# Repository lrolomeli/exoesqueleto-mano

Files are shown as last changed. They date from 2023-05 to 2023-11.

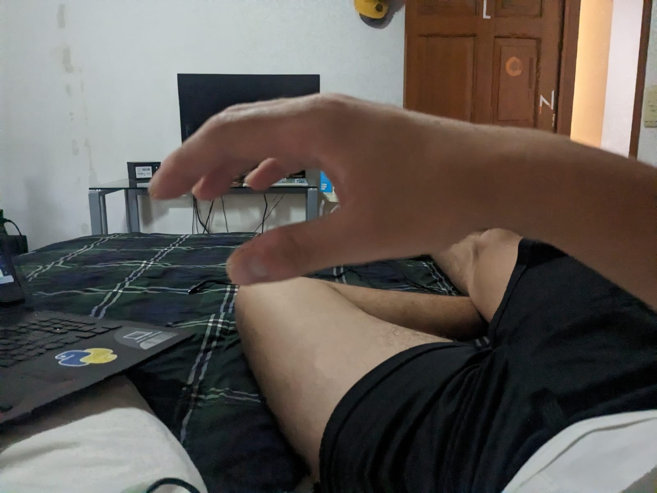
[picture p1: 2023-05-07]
imagenes/manoreal.jpeg

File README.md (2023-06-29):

# exoesqueleto-mano
Proyecto de biomédica, exoesqueleto motorizado para rehabilitación;
Interfaz Grafica Pyside Python,
Comunicacion Serial a través de módulo bluetooth serial HC-06,
Modelado en 3D en SolidWorks 2020, 
Impresion 3D Software Ultimaker Cura 4.13.1,
Software Embebido Diseñado en STM32 CubeIDE 1.12.1 HAL API BareMetal,
microcontrolador BluePill STM32F103C8T6,
controlador de motor a pasos A4988.
Bateria 12v motores de pasos de 12v y PCB diseñada en easyeda

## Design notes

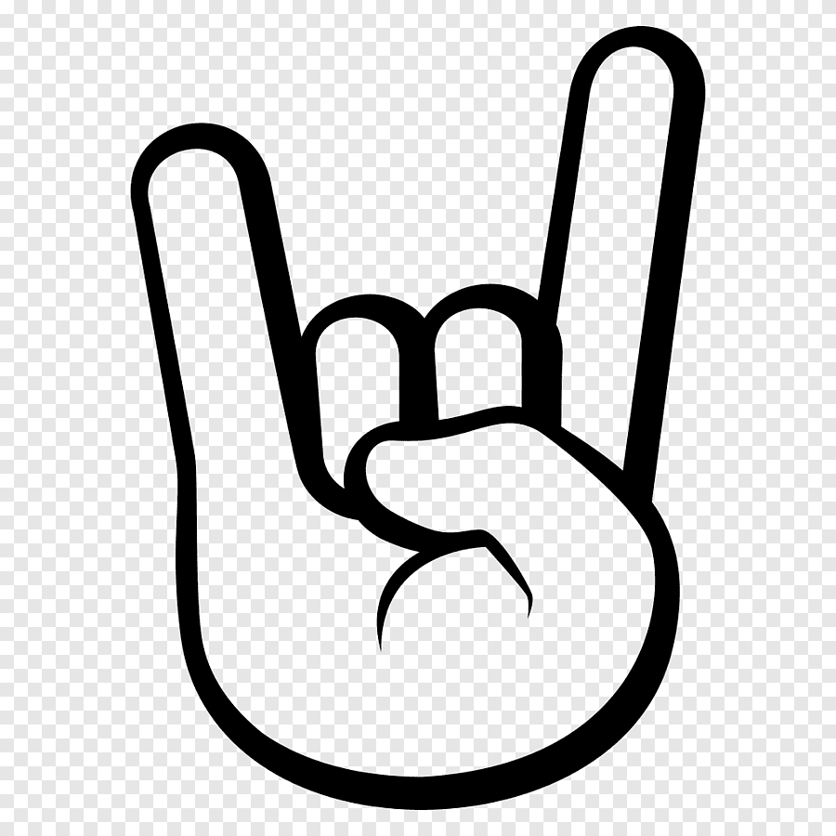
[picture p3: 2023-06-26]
programacion/pythongui/rockll.png

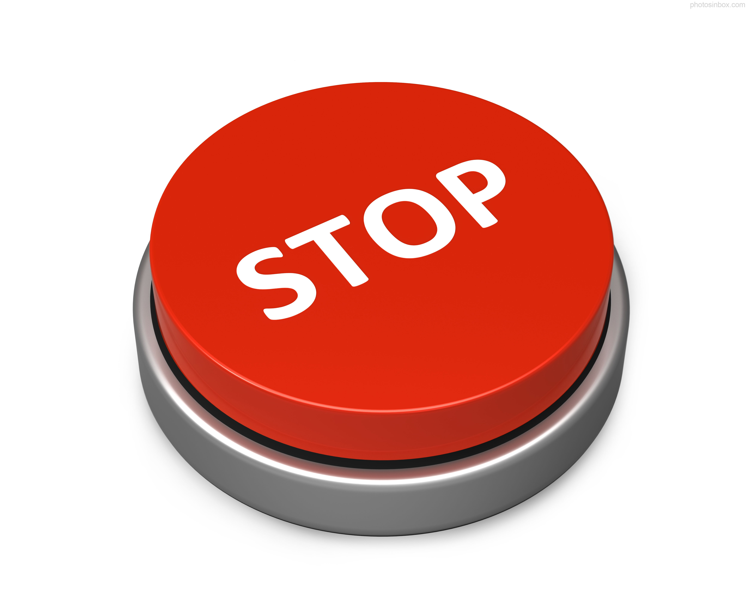
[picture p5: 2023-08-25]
programacion/pythongui/stop.png

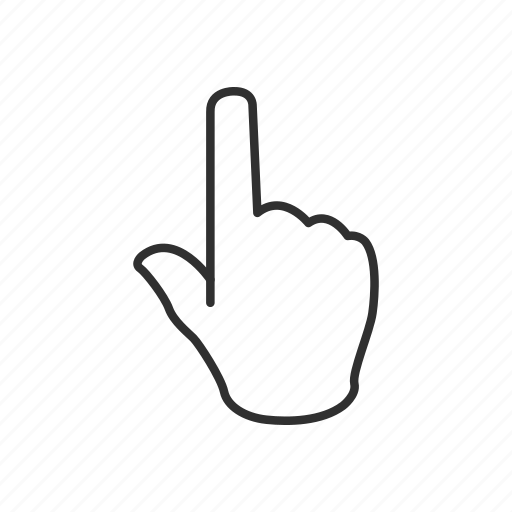
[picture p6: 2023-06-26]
programacion/pythongui/fup.png

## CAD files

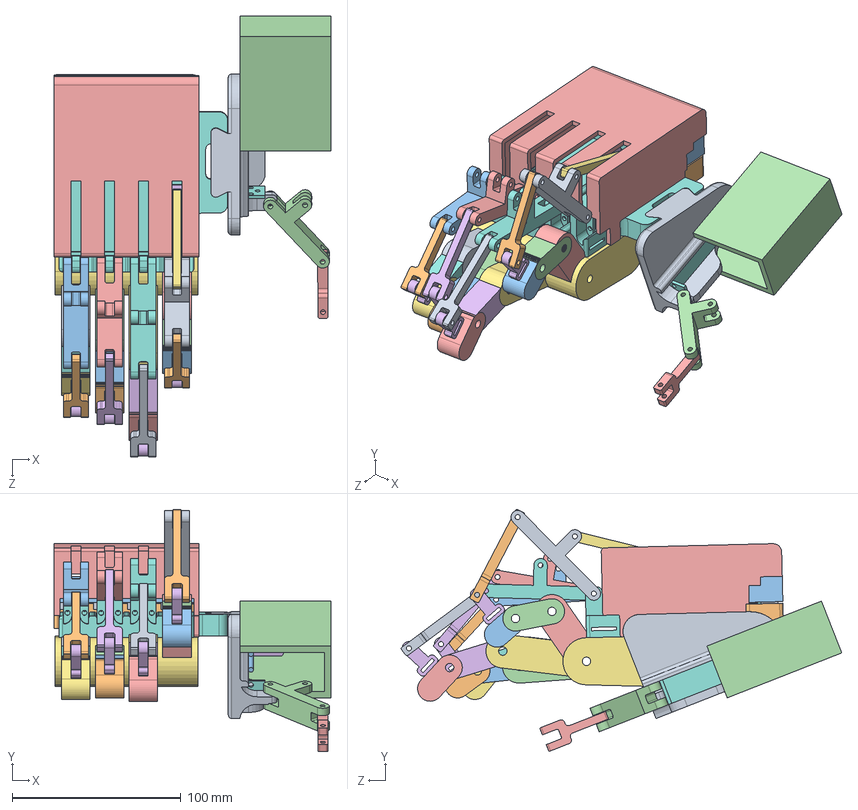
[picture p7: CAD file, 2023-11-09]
ensamble/ens_exo_unapieza.SLDASM
164.3 x 143.6 x 261.3 mm
palanca-indice
vastago-y-largo-indice
f1-indice
f2-indice
f3-indice
falangefinal x 4
vastago
guia-lineal x 5
motor15mm x 5
tornillo
perno-lineal x 4
union-motor_original
f1-medio
f2-medio
f3-medio
palanca-medio
vastago-y-largo-medio
f1-anular
f2-anular
f3-anular
palanca-anular
vastago-y-largo-anular
f1-menique
f2-menique
f3-menique
vastago-y-largo-menique
palanca-menique
_palanca-menique
vastago-y-largo-pulgar
abrazadera
torso-mano
base-principal-completa
base-principal-p2
abrazadera_completa_2pza
abrazadera_completa
cubierta_p
entronque

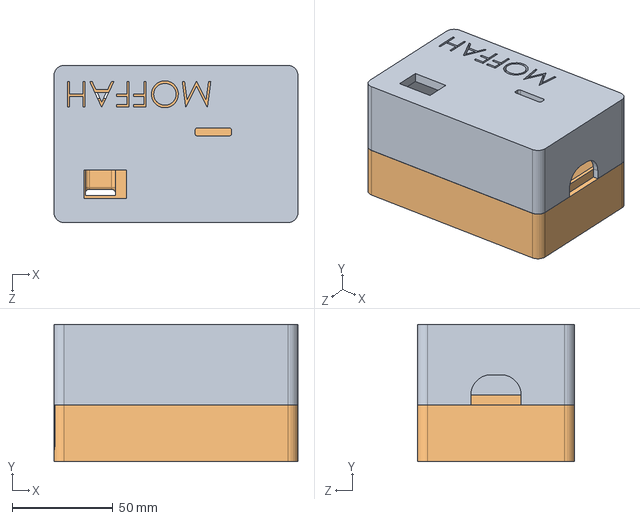
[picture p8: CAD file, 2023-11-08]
ensamble/ensamble base.SLDASM
121.0 x 68.1 x 78.0 mm
tapa_base
base_bateria_pcb_copia

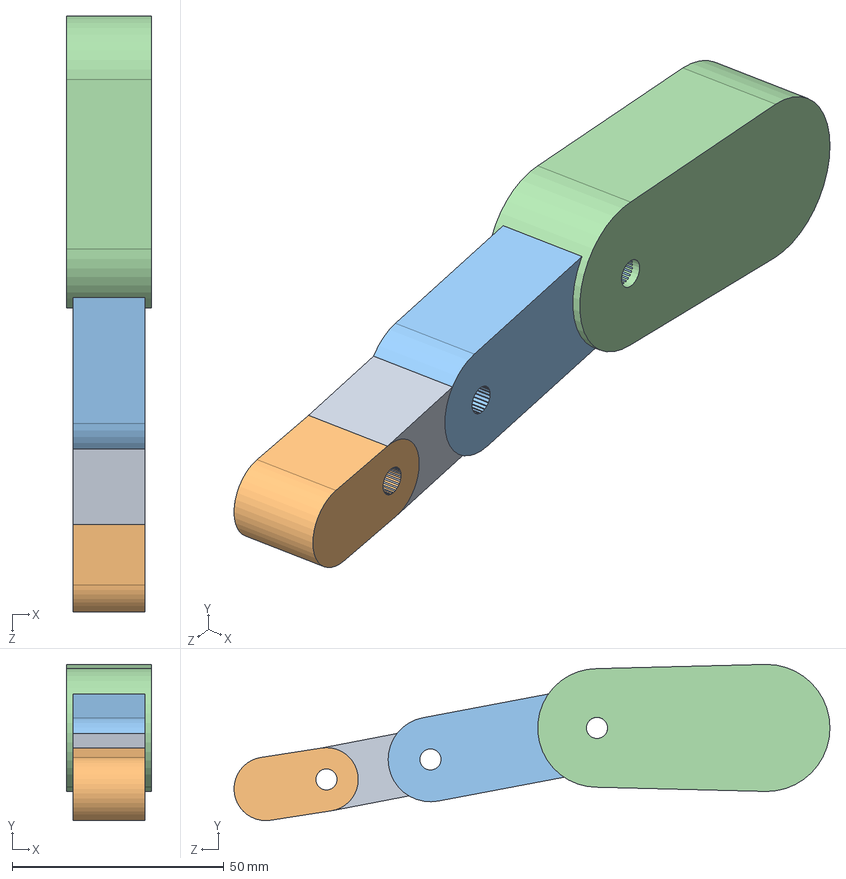
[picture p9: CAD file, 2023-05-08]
mano_p/Mano_p.SLDASM
20.0 x 36.9 x 140.7 mm
falange2_p
falange1_p
falange3_p
falange4_p

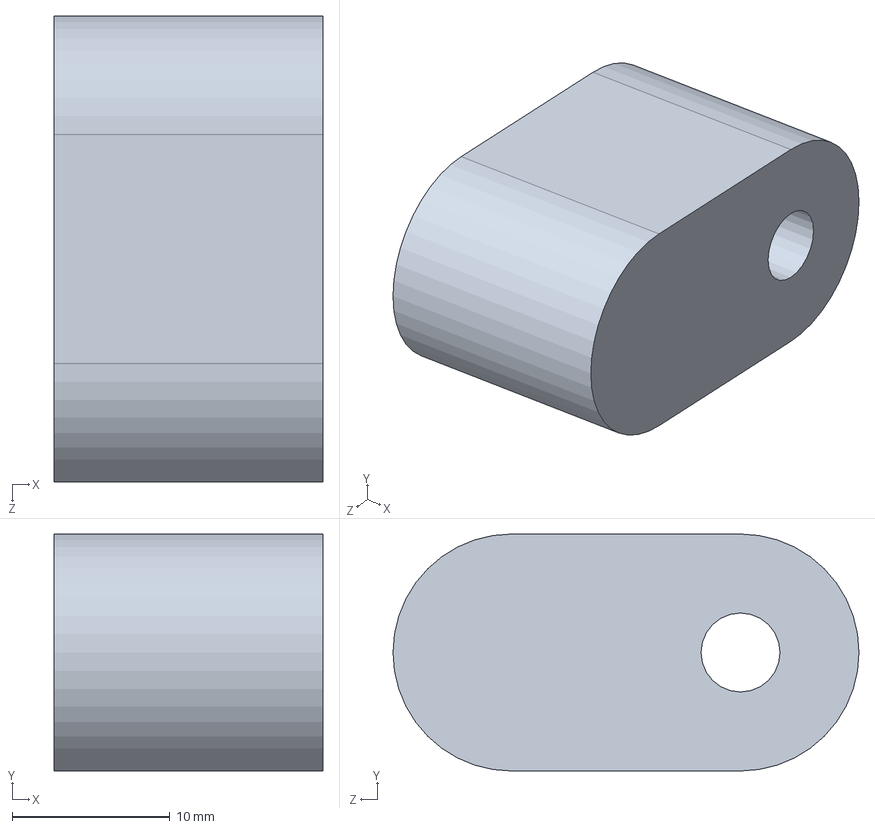
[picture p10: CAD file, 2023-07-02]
mano_p/f1-indice.SLDPRT
17.0 x 15.0 x 29.5 mm

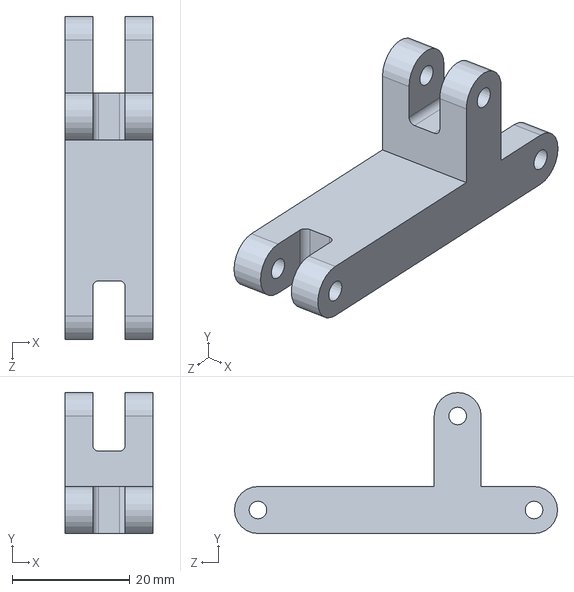
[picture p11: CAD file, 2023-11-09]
piezas/_palanca-menique.SLDPRT
15.0 x 24.0 x 55.0 mm

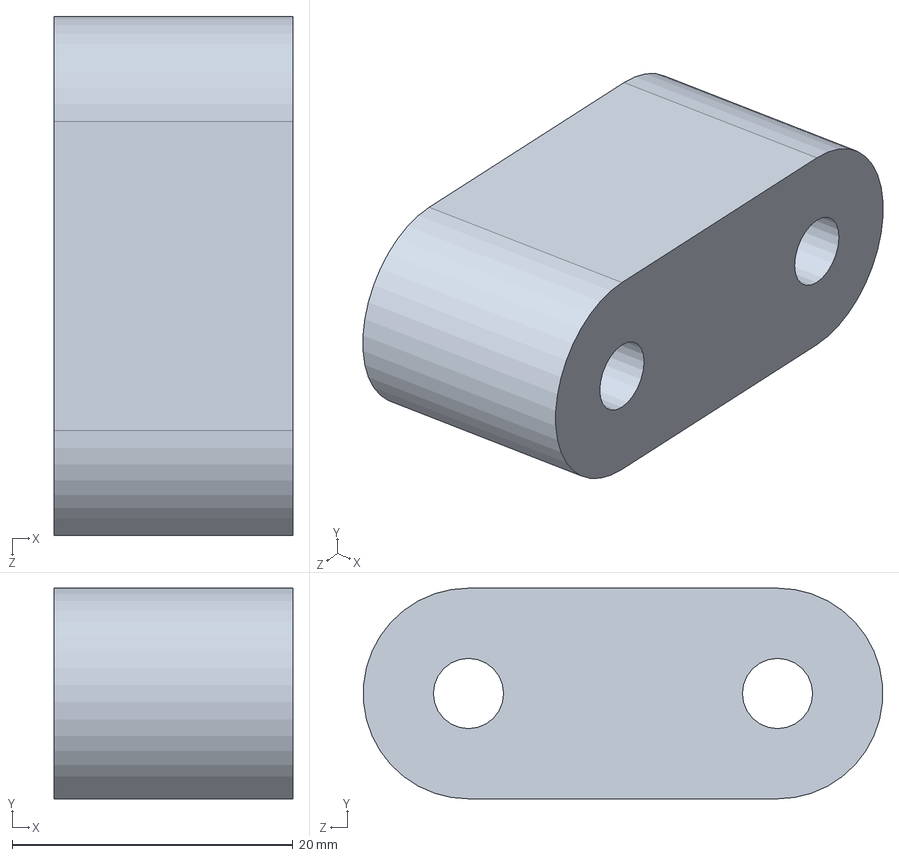
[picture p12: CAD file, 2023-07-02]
mano_p/f2-indice.SLDPRT
17.0 x 15.0 x 36.9 mm

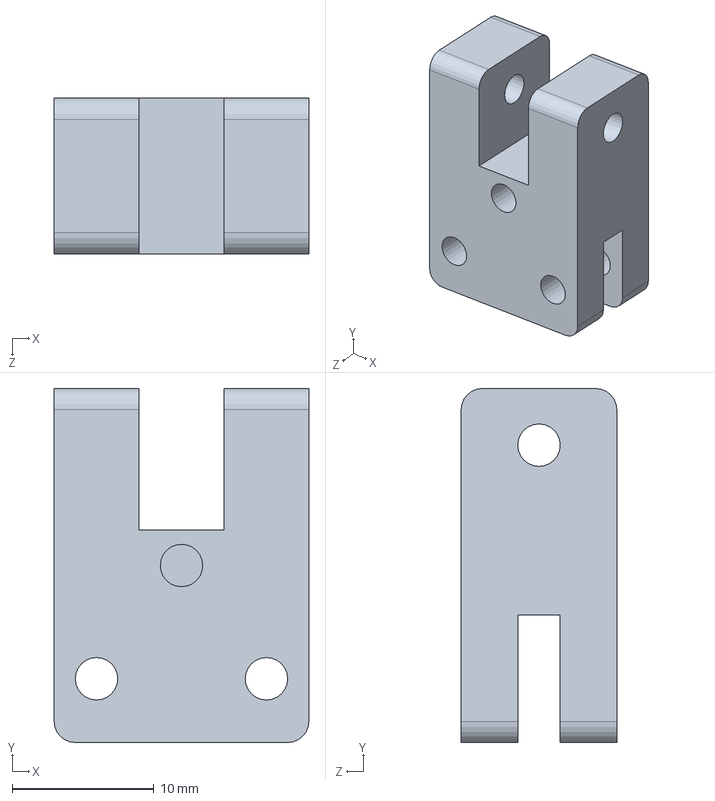
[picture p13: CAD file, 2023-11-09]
piezas/entronque.SLDPRT
18.0 x 25.0 x 11.0 mm

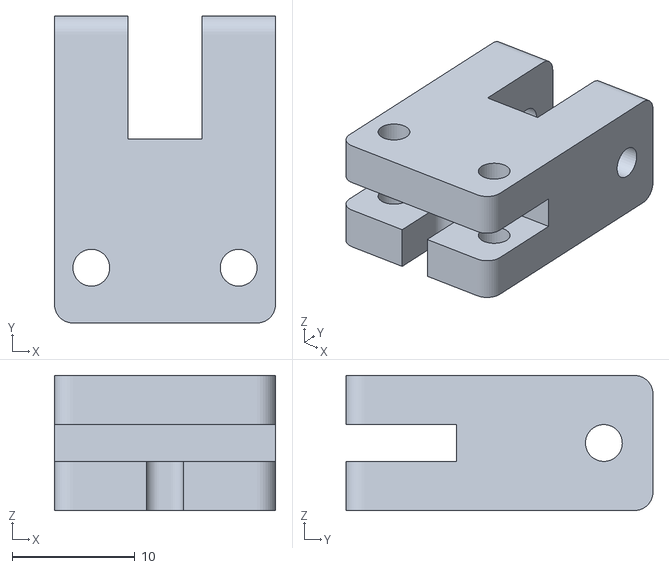
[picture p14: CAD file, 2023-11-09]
stl_impresion/entronque.STL
18.0 x 25.0 x 11.0

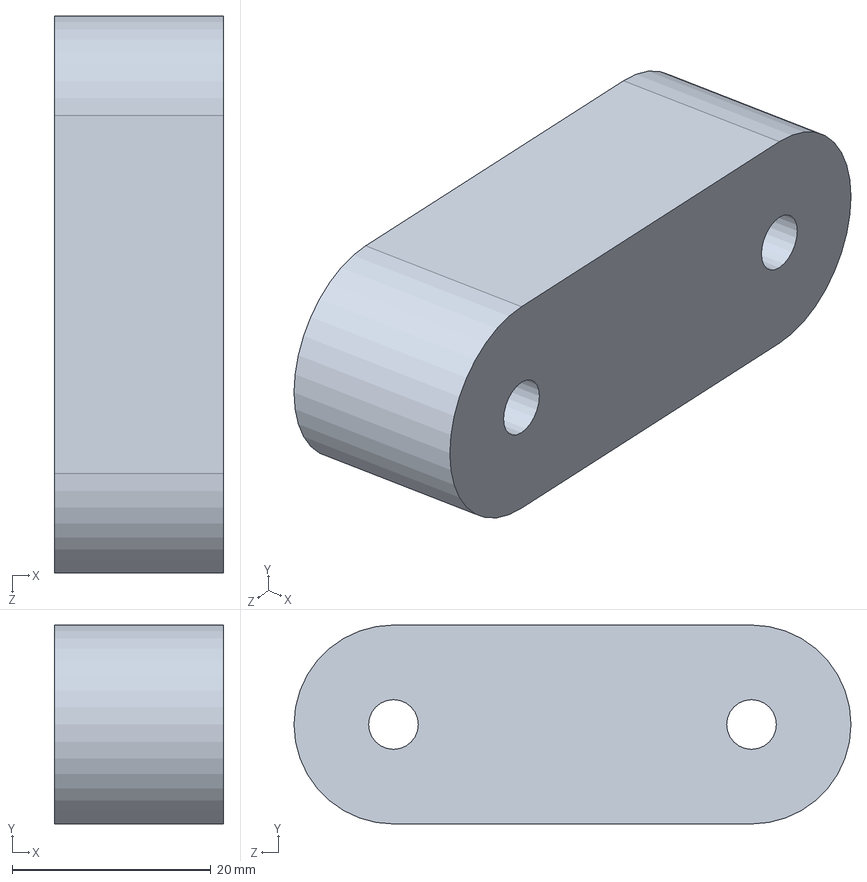
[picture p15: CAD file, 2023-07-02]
mano_p/f3-indice.SLDPRT
17.0 x 20.0 x 56.0 mm

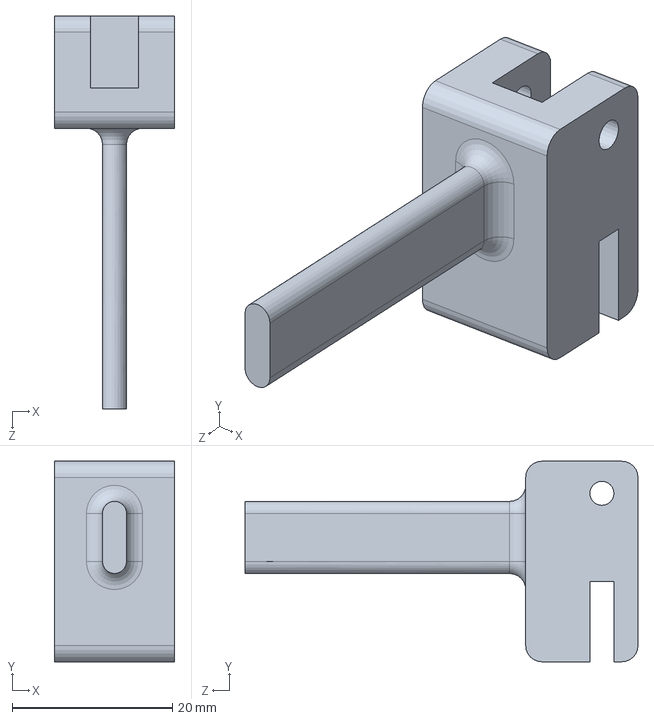
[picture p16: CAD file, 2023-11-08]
piezas/entronque_alto.SLDPRT
15.0 x 25.0 x 49.0 mm

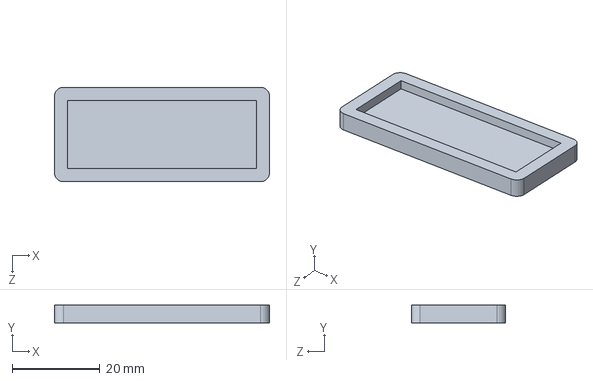
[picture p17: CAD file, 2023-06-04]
mano_p/reposamotor.SLDPRT
49.0 x 4.00 x 21.5 mm

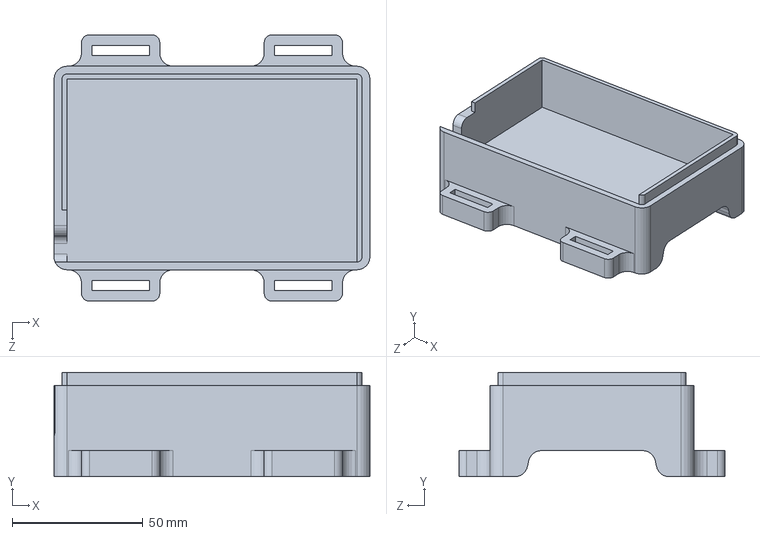
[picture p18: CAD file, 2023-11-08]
piezas/base_bateria_pcb.SLDPRT
121.0 x 40.0 x 102.0 mm

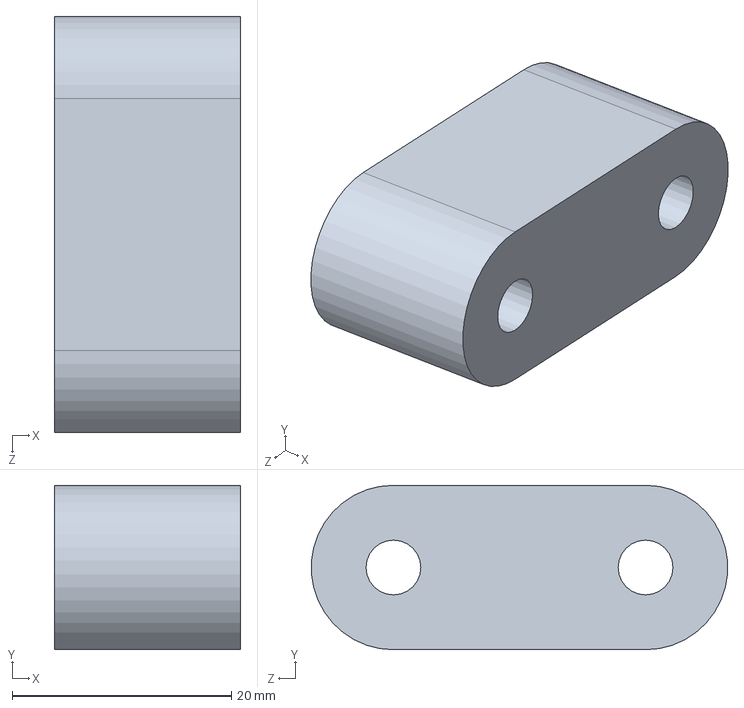
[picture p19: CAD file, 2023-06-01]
mano_p/f2-menique.SLDPRT
17.0 x 15.0 x 37.9 mm

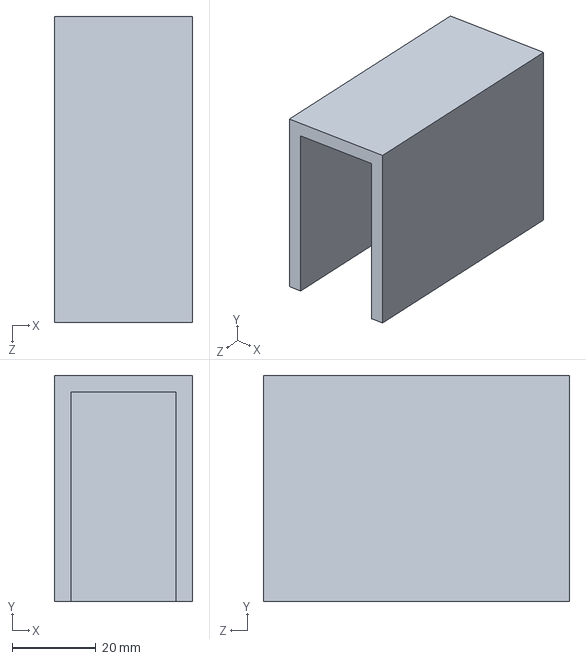
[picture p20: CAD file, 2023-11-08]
piezas/cubierta_p.SLDPRT
33.0 x 54.0 x 73.0 mm

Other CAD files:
stl_impresion/_palanca-menique.STL
stl_impresion/entronque_alto.STL
stl_impresion/cubierta1.STL
mano_p/f3-medio.SLDPRT
mano_p/f1-anular.SLDPRT
mano_p/f1-medio.SLDPRT
mano_p/f1-menique.SLDPRT
mano_p/f2-anular.SLDPRT
mano_p/f2-medio.SLDPRT
mano_p/f3-anular.SLDPRT
mano_p/f3-menique.SLDPRT
mano_p/falange4_p.SLDPRT
mano_p/torso-mano.SLDPRT
piezas/abrazadera.SLDPRT
piezas/abrazadera_completa.SLDPRT
piezas/abrazadera_completa_2pza.SLDPRT
piezas/base-principal-completa.SLDPRT
piezas/base-principal-p2.SLDPRT
piezas/base_bateria_pcb_copia.SLDPRT
piezas/cincho_belcro.SLDPRT
piezas/cubierta.SLDPRT
piezas/cubierta1.SLDPRT
piezas/entronque_barra_ref.SLDPRT
piezas/falangefinal.SLDPRT
piezas/guia-lineal.SLDPRT
piezas/motor15mm.SLDPRT
piezas/palanca-anular.SLDPRT
piezas/palanca-indice.SLDPRT
piezas/palanca-medio.SLDPRT
piezas/palanca-menique.SLDPRT
piezas/palanca-pulgar.SLDPRT
piezas/perno-lineal.SLDPRT
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

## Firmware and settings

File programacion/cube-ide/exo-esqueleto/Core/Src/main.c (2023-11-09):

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
/* Includes ------------------------------------------------------------------*/
#include "main.h"
#include "tim.h"
#include "usart.h"
#include "gpio.h"

/* USER CODE BEGIN PTD */
typedef enum{
	empty = 0,
	full
}enum_buffer_status;

typedef enum{
	Up = 0,
	Down,
	None
}enum_motion;

typedef enum{
	No = 0,
	Yes
}enum_bit_state;

typedef enum{
	Unreferenced = 0,
	Referenced
}enum_referenced;

typedef enum{
	GoHome = 0,
	WaitReleaseStage,
	GoInitialPosition,
	HomeRoutineComplete,
}enum_home_stages;


typedef enum{
	not_used = 0x00,
	reference_routine = 0x01,
	all_way_down  = 0x02,
	all_way_up  = 0x03,
	sinewave  = 0x04,
	gotoposition  = 0x05,
	reserved_plus=0x2B,
	reserved_minus=0x2D,
	reserved_major_C = 0x43,
	reserved_major_D = 0x44,
	nothing=0x74,
	deselect_thumb = 0x75,
	deselect_index = 0x76,
	deselect_middle = 0x77,
	deselect_ring = 0x78,
	deselect_little = 0x79,
	select_thumb = 0x7A,
	select_index = 0x7B,
	select_middle = 0x7C,
	select_ring = 0x7D,
	select_little = 0x7E,
	stop = 0x7F,
	speed_0 = 0xFA,
	speed_1 = 0xFB,
	speed_2 = 0xFC,
	speed_3 = 0xFD,
	speed_4 = 0xFE,
	speed_5 = 0xFF
}enum_action;

typedef enum{
	lost = 0,
	home,
	referenced
}enum_motor_status;

typedef enum{
	thumb = 0,
	index,
	middle,
	ring,
	little,
	flength
}enum_fingers;

typedef enum{
	portA = 0,
	portB,
}enum_ports;

typedef enum{
	normal = 0,
	fast = 1,
	as_hell

}enum_speed;

typedef enum{
	home_fs = 0,
	idle_fs,

}enum_fsm_state;

typedef struct{
	enum_bit_state in_operation;
	enum_fsm_state fsm_state;
	uint8_t bluetooth_command;
}st_exoesk;

typedef struct{
	uint16_t current_pos[flength];
	uint16_t go_to[flength];
	enum_bit_state fingers_in_op[flength];
	enum_bit_state fingers_in_pos[flength];
}st_gfinger_params;

typedef struct{
	const uint8_t port;
	const uint16_t pin;
}st_gpio_config_t;

typedef struct {
	const st_gpio_config_t step;
	const st_gpio_config_t direction;
	const st_gpio_config_t sleep;
}st_fconfig;

typedef void(*func_ptr_t)(st_exoesk * exoesk);

/* USER CODE END PTD */

/* USER CODE BEGIN PD */
//#define test

/* USER CODE END PD */


/* USER CODE BEGIN PV */

static const st_fconfig exoconfig[flength] = {
	/*       steps               direction                sleep                 home          */
	{ {portA, GPIO_PIN_1}, 	{portA, GPIO_PIN_0},   {portB, GPIO_PIN_4},	},//thumb
	{ {portB, GPIO_PIN_14},	{portB, GPIO_PIN_13},  {portB, GPIO_PIN_15}, },//index
	{ {portB, GPIO_PIN_1}, 	{portB, GPIO_PIN_0},   {portA, GPIO_PIN_8},	},//middle
	{ {portA, GPIO_PIN_6}, 	{portA, GPIO_PIN_5},   {portA, GPIO_PIN_7},	},//ring
	{ {portA, GPIO_PIN_3}, 	{portA, GPIO_PIN_2},   {portB, GPIO_PIN_3} }//little
};

static uint8_t times = 0;
static volatile uint8_t timeout_flg = 0;
static volatile enum_motor_status home_routine[flength] = {lost};
static volatile enum_buffer_status buffer_status = empty;
static volatile st_gfinger_params gfinger_params = { {0},{0},{0},{0} };

/* USER CODE END PV */

void SystemClock_Config(void);
/* USER CODE BEGIN PFP */

static void set_direction(uint8_t finger, GPIO_PinState dir);
static void sleep_motor(uint8_t finger);
static void motor_wakeup(uint8_t finger);
static void send_pulse(uint8_t finger);
static void clean_buffer(uint8_t * buf);
static void sinewave_fn(st_exoesk * exoesk);
static void preset_fingers_target(st_exoesk * exoesk, uint16_t position);
static void alive_fn(void);
static void send_step_pulses(st_exoesk * exoesk);
static void select_all_fingers(st_exoesk * exoesk);
static void deselect_all_fingers(st_exoesk * exoesk);
static void prepare_action(st_exoesk * exoesk);
static void dynamics(st_exoesk * exoesk);
static void home_f(st_exoesk * exoesk);
static void idle_f(st_exoesk * exoesk);
static void finger_default_conditions();
static uint8_t process_cmd(st_exoesk * exoesk);
static uint8_t fingers_in_position(void);
static void emergency_stop(void);
static void sleep_all_fingers(void);

/* USER CODE END PFP */

/* USER CODE BEGIN 0 */

static const func_ptr_t fsm_state[2] = {home_f, idle_f};

void HAL_UART_RxCpltCallback(UART_HandleTypeDef *huart){
	//waits until buffer is empty again
	if(empty == buffer_status)
	{
		buffer_status = full;
	}
}

void HAL_TIM_PeriodElapsedCallback(TIM_HandleTypeDef * htim)
{
	if(htim->Instance == TIM3)
	{
		if(timeout_flg==0)
		{
			timeout_flg = 1;
		}

	}

}

/* USER CODE END 0 */

/**
  * @brief  The application entry point.
  * @retval int
  */
int main(void)
{
  /* USER CODE BEGIN 1 */
	uint8_t halfms_cnt=0;
	st_exoesk exoesk = {No, home_fs, 0};
  /* USER CODE END 1 */

  /* MCU Configuration--------------------------------------------------------*/

  /* Reset of all peripherals, Initializes the Flash interface and the Systick. */
  HAL_Init();

  /* Configure the system clock */
  SystemClock_Config();

  /* Initialize all configured peripherals */
  MX_GPIO_Init();
  MX_USART3_UART_Init();
  MX_TIM3_Init();
  /* USER CODE BEGIN 2 */

	HAL_UART_Receive_IT(&huart3, &exoesk.bluetooth_command, sizeof(exoesk.bluetooth_command));
	htim3.Init.Period = htim3.Init.Period >> (normal);
	HAL_TIM_Base_Start_IT(&htim3);
	HAL_GPIO_WritePin(GPIOA, GPIO_PIN_4, GPIO_PIN_RESET);
	finger_default_conditions();
  /* USER CODE END 2 */

  /* Infinite loop */
  /* USER CODE BEGIN WHILE */
	while (1)
	{

		fsm_state[exoesk.fsm_state](&exoesk);

		if(timeout_flg)
		{

			if (halfms_cnt < times)
			{

				halfms_cnt++;
			}
			else
			{
				dynamics(&exoesk);
				halfms_cnt = 0;
			}
			alive_fn();
			timeout_flg = 0;

		}
    /* USER CODE END WHILE */

    /* USER CODE BEGIN 3 */
	}
  /* USER CODE END 3 */
}

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
/* USER CODE BEGIN 4 */

static void home_f(st_exoesk * exoesk)
{
	static enum_home_stages home_stage = GoHome;
	uint8_t finger = thumb;

	switch(home_stage)
	{
	case GoHome:
		// Seleccionamos los dedos que queremos mover en este caso todos.
		select_all_fingers(exoesk);
		// Situacion actual nos encontramos en la posicion 4095
		// Objetivo: movernos hacia la posicion CERO (0) (home)
		preset_fingers_target(exoesk, ZERO_POSITION);
		// Esperar a que se despejen los motores
		home_stage = WaitReleaseStage;
		break;
	case WaitReleaseStage:
		if(No == exoesk->in_operation)
		{
			// Definimos el objetivo al que hay que movernos. Los pasos necesarios para volver al boton
			preset_fingers_target(exoesk, HOME_POSITION);
			home_stage = GoInitialPosition;
		}
		break;

	case GoInitialPosition:
		if(No == exoesk->in_operation)
		{
			for(finger=thumb; finger<flength; finger++)
			{
				home_routine[finger] = referenced;
			}
			deselect_all_fingers(exoesk);
			home_stage = HomeRoutineComplete;
			exoesk->fsm_state = idle_fs;
		}
		break;
	case HomeRoutineComplete:
		// Comenzamos con condiciones iniciales
		finger_default_conditions();
		home_stage = GoHome;
		break;
	default:
		break;
	}

}

static void idle_f(st_exoesk * exoesk)
{

	if(full == buffer_status)
	{
		prepare_action(exoesk);
		clean_buffer(&exoesk->bluetooth_command);
		HAL_UART_Receive_IT(&huart3, &exoesk->bluetooth_command, sizeof(exoesk->bluetooth_command));
	}

}

static void dynamics(st_exoesk * exoesk)
{
	if(exoesk->in_operation)
	{
		/* Move fingers */
		send_step_pulses(exoesk);
	}

}

static void prepare_action(st_exoesk * exoesk)
{
	static uint8_t cmd_complete = 1;
	uint16_t steps = 0;

	if(cmd_complete == 0)
	{
		steps = exoesk->bluetooth_command * 25;
		preset_fingers_target(exoesk, (steps<<SYS_USED_STEP));
		cmd_complete = 1;
	}
	else
	{
		cmd_complete = process_cmd(exoesk);
	}
}

static uint8_t process_cmd(st_exoesk * exoesk)
{
	switch(exoesk->bluetooth_command)
	{
	case not_used:
		break;
	case reference_routine:
		exoesk->fsm_state = home_fs;
		break;
	case all_way_down:
		preset_fingers_target(exoesk, ZERO_POSITION);
		break;
	case all_way_up:
		preset_fingers_target(exoesk, MAX_POSITION);
		break;
	case sinewave:
		sinewave_fn(exoesk);
		break;
	case gotoposition:
		return 0;
		break;
	case reserved_major_C:
		break;
	case deselect_thumb:
		gfinger_params.fingers_in_op[thumb] = No;
		break;
	case deselect_index:
		gfinger_params.fingers_in_op[index] = No;
		break;
	case deselect_middle:
		gfinger_params.fingers_in_op[middle] = No;
		break;
	case deselect_ring:
		gfinger_params.fingers_in_op[ring] = No;
		break;
	case deselect_little:
		gfinger_params.fingers_in_op[little] = No;
		break;
	case select_thumb:
		gfinger_params.fingers_in_op[thumb] = Yes;
		break;
	case select_index:
		gfinger_params.fingers_in_op[index] = Yes;
		break;
	case select_middle:
		gfinger_params.fingers_in_op[middle] = Yes;
		break;
	case select_ring:
		gfinger_params.fingers_in_op[ring] = Yes;
		break;
	case select_little:
		gfinger_params.fingers_in_op[little] = Yes;
		break;
	case stop:
		sleep_all_fingers();
		exoesk->in_operation = No;

		break;
	case speed_1:
	case speed_2:
	case speed_3:
	case speed_4:
	case speed_5:
		times = exoesk->bluetooth_command - speed_0;
		break;
	default:
		break;
	}
	return 1;

}

static void select_all_fingers(st_exoesk * exoesk)
{
	for(uint8_t finger=thumb; finger<flength; finger++)
	{
		gfinger_params.fingers_in_op[finger] = Yes;
	}
}

static void deselect_all_fingers(st_exoesk * exoesk)
{
	for(uint8_t finger=thumb; finger<flength; finger++)
	{
		gfinger_params.fingers_in_op[finger] = No;
	}
}

static void sleep_all_fingers(void)
{
	for(uint8_t finger=thumb; finger<flength; finger++)
	{
		sleep_motor(finger);
	}
}

static void send_step_pulses(st_exoesk * exoesk)
{
	uint8_t finger = thumb;
	for(finger = thumb; finger < flength; finger++)
	{
		if(gfinger_params.fingers_in_op[finger])
		{
			/* when finger is selected to be moved */
			if(gfinger_params.go_to[finger] == gfinger_params.current_pos[finger])
			{
				/* when finger has reached expected position */
				sleep_motor(finger);
				gfinger_params.fingers_in_pos[finger] = Yes;
			}
			else
			{
				/* finger has not reached expected position */
				send_pulse(finger);
				if(gfinger_params.go_to[finger] > gfinger_params.current_pos[finger])
				{
					gfinger_params.current_pos[finger]++;
				}
				else
				{
					gfinger_params.current_pos[finger]--;
				}
			}
		}
	}

	/* if all fingers are in position we should sleep the system */
	if(fingers_in_position())
	{
		exoesk->in_operation = No;
	}
	else
	{
		exoesk->in_operation = Yes;
	}

}

static void alive_fn(void)
{
	static uint16_t var = 2000;

	if(var > 0)
	{
		var--;
	}
	else
	{
		var = 2000;
		HAL_GPIO_TogglePin(GPIOC, GPIO_PIN_13);
	}
}

static void finger_default_conditions()
{
	for(uint8_t finger=thumb; finger<flength; finger++)
	{
		/* el dedo no esta en operacion */
		gfinger_params.fingers_in_op[finger] = No;
		/* la rutina de home no se ha completado */
		home_routine[finger] = lost;
		/* no se conoce la posicion del motor */
		gfinger_params.current_pos[finger] = SCREW_LEN_IN_STEP;
		/* no se ha determinado la posicion a la que vamos a movernos */
		gfinger_params.go_to[finger] = ZERO_POSITION;
		/* el dedo esta en cierta posicion y por lo tanto no se esta moviendo */
		gfinger_params.fingers_in_pos[finger] = Yes;
	}
}

static void sinewave_fn(st_exoesk * exoesk)
{

}

/**
 * preset_fingers_target function
 *
 * 1) Revisa cual dedo se encuentra habilitado para moverse.
 * 2) Establece el objetivo al que hay que mover cada dedo
 * 3)
 *
 */
static void preset_fingers_target(st_exoesk * exoesk, uint16_t position)
{
	uint8_t finger = thumb;
	for(finger=thumb; finger<flength; finger++)
	{
		if(gfinger_params.fingers_in_op[finger])
		{
			gfinger_params.fingers_in_pos[finger] = No;
			gfinger_params.go_to[finger] = position;
			// opc1 -> si la posicion actual es mayor a la posicion final
			if (gfinger_params.current_pos[finger] > position)
			{
				set_direction(finger, Down);
				motor_wakeup(finger);
			}
			else if(gfinger_params.current_pos[finger] < position)
			{
				// si la posicion final es mayor al maximo
				if(MAX_POSITION < position)
				{
					gfinger_params.go_to[finger] = MAX_POSITION;
				}
				set_direction(finger, Up);
				motor_wakeup(finger);
			}
			else
			{
				// current position is not the same as goto position
				gfinger_params.go_to[finger] = gfinger_params.current_pos[finger];
				gfinger_params.fingers_in_pos[finger] = Yes;
			}
		}
	}

	/* if all fingers are in position we should do nothing */
	if(fingers_in_position())
	{
		exoesk->in_operation = No;
	}
	else
	{
		exoesk->in_operation = Yes;
	}

}

static uint8_t fingers_in_position()
{
	return (gfinger_params.fingers_in_pos[thumb] &&
			gfinger_params.fingers_in_pos[index] &&
			gfinger_params.fingers_in_pos[middle] &&
			gfinger_params.fingers_in_pos[ring] &&
			gfinger_params.fingers_in_pos[little]);
}

static void clean_buffer(uint8_t * buf)
{
	*buf = 0;
	buffer_status = empty;
}

static void emergency_stop(void)
{
	HAL_GPIO_WritePin(GPIOA, GPIO_PIN_4, GPIO_PIN_SET);
}

static void sleep_motor(uint8_t finger)
{
	if(exoconfig[finger].sleep.port == portA)
		HAL_GPIO_WritePin(GPIOA, exoconfig[finger].sleep.pin, GPIO_PIN_RESET);
	else
		HAL_GPIO_WritePin(GPIOB, exoconfig[finger].sleep.pin, GPIO_PIN_RESET);
}

static void motor_wakeup(uint8_t finger)
{
	if(exoconfig[finger].sleep.port == portA)
		HAL_GPIO_WritePin(GPIOA, exoconfig[finger].sleep.pin, GPIO_PIN_SET);
	else
		HAL_GPIO_WritePin(GPIOB, exoconfig[finger].sleep.pin, GPIO_PIN_SET);
}

static void send_pulse(uint8_t finger)
{
	if(exoconfig[finger].step.port == portA)
		HAL_GPIO_TogglePin(GPIOA, exoconfig[finger].step.pin);
	else
		HAL_GPIO_TogglePin(GPIOB, exoconfig[finger].step.pin);
}

static void set_direction(uint8_t finger, GPIO_PinState dir)
{

	if(exoconfig[finger].direction.port == portA)
		HAL_GPIO_WritePin(GPIOA, exoconfig[finger].direction.pin, dir);
	else
		HAL_GPIO_WritePin(GPIOB, exoconfig[finger].direction.pin, dir);
}

/* USER CODE END 4 */
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


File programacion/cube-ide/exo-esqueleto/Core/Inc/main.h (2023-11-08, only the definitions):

#define Full_Step 		(0U)
#define Half_Step 		(1U)
#define Quarter_Step 	(2U)
#define Eigth_Step 		(3U)
#define Sixteen_Step 	(4U)
#define SYS_USED_STEP (Half_Step)
#define SCREW_LEN_IN_STEP ((4095)<<(SYS_USED_STEP))
#define Initial_Position 	((3000U)<<(SYS_USED_STEP))
#define HOME_POSITION 		((300U)<<(SYS_USED_STEP))
#define UNDEFINED 		((4095U)<<(SYS_USED_STEP))
#define NOT_KNOWN_POSITION (0U)
#define MAX_POSITION 	((3200U)<<(SYS_USED_STEP))
#define ZERO_POSITION 	(0U)

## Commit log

2023-04-27 primer registro de las piezas del exoesqueleto, ensamble y archivos de impresion
    [coplemotor_tornillo.SLDPRT, coplemotor_tornillo.STL, ensamble-exoesqueleto.SLDASM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]
2023-04-27 ruta relativa de archivos de piezas del ensamble agregada
    [ensamble-exoesqueleto.SLDASM]
2023-05-07 new branch to make my design ideas
    [ensamble-exoesqueleto.SLDASM, falange.SLDPRT, falange_s.SLDPRT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]
2023-05-07 nuevos cambios
    [ensamble-exoesqueleto.SLDASM, falange.SLDPRT, soporte de union.SLDPRT]
2023-05-07 rediseño de exoesqueleto
    [ensamble-exoesqueleto.SLDASM, soporte de falange.SLDPRT, soporte de union.SLDPRT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]
2023-05-08 falange dinamica
    [ensamble-exoesqueleto.SLDASM, falange.SLDPRT, falange.STL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]
2023-05-08 palanca funcionando
    [Mano_p.SLDASM, conector.SLDPRT, ensamble-exoesqueleto.SLDASM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]
2023-05-08 cambio de nombre a base principal
    [base-principal.SLDPRT, base-principal.STL, ensamble-exoesqueleto.SLDASM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]
2023-05-20 ensamble mano completa
    [ensamble-exocompleto.SLDASM, ensamble-exoesqueleto.SLDASM, falange.SLDPRT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]
2023-05-20 modificaciones al diseño ampliar medidas en puntos criticos de impresion como los cortes circulares ampliar ajustes de piezas ensambladas corregir la pieza vastago en y alargar el palo centrar mas el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
    [ensamble-exocompleto.SLDASM, falange.SLDPRT, palanca-falange.SLDPRT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]
2023-05-29 ensamble modificado, programa v0.0 comenzado
    [base-principal-completa.SLDPRT, base-principal.STL, coplemotor_tornillo.STL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]
2023-05-29 programa 1 mover motor casi listo
2023-06-01 prototipo final dedos listos falta pulgar
    [base-principal-completa.SLDPRT, base-principal.SLDPRT, conector.SLDPRT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]
2023-06-01 pulgar agregado al ensamble
    [base-principal-completa.SLDPRT, ens_exo_unapieza.SLDASM, guia-lineal.SLDPRT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]
2023-06-04 cambios en el codigo
    [base-principal-completa.SLDPRT, ens_exo_unapieza.SLDASM, reposamotor.SLDPRT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]
2023-06-04 codigo under test uart enable off
2023-06-05 interrupciones externas para botones de home listas, motor en prueba movimiento continuo, comunicacion bluetooth lista, pwm listo por si se necesita, timer para frecuencia del motor 1ms
2023-06-09 programa listo para mover un dedo con comandos bluetooth
2023-06-12 fixes en la rutina de referencia en codigo, piezas nuevas para fijar push buttons fisicos y de referencia a posicion cero
2023-06-12 modificaciones al ensamble y piezas nuevas
    [abrazadera.SLDPRT, abrazadera.STL, ens_exo_unapieza.SLDASM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]
2023-06-12 division en piezas de base principal
    [base-principal-completa.SLDPRT, base-principal-p1.SLDPRT, base-principal-p1.STL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]
2023-06-12 nuevo diseño pieza base principal
    [base-principal-p1.SLDPRT]
2023-06-12 ensamble sin errores nueva base pieza principal
    [_base-principal-completa.SLDPRT, base-principal-completa.SLDPRT, base-principal-p1.SLDPRT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]
2023-06-16 base principal 2da pieza lista
    [_base-principal-completa.SLDPRT, base-principal-completa.SLDPRT, base-principal-p2.SLDPRT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]
2023-06-24 quitando senales pwm que no se necesitan
2023-06-24 desconfiguracion pwm de los pines
2023-06-25 modificaciones en el codigo para agregar mas motores y entradas
2023-06-26 interfaz de usuario lista
2023-06-28 campos de bits reemplazados por arreglo de enteros, mas faciles de utilizar y dar mantenimiento
2023-06-29 there are still bugs when referencing or going back and forth
    [exoesqueleto.py, gui.py, main.c]
2023-06-29 fixed logic to home reference
    [main.c]
2023-06-29 limpiando piezas desactualizadas del ensamble
    [ens_exo_unapieza.SLDASM, palanca-anular.SLDPRT, palanca-medio.SLDPRT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]
2023-06-30 entronque modificado
    [ens_exo_unapieza.SLDASM, entronque_alto.SLDPRT, entronque_barra_ref.SLDPRT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]
2023-06-30 eliminando archivos no utilizados en el ensamble
    [_base-principal-completa.SLDPRT, coplemotor_tornillo.SLDPRT, ens_exo_unapieza.SLDASM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]
2023-06-30 eliminando archivos temporales de impresion y 2d
    [abrazadera.STL, base-principal-p1.STL, base-principal-p2.STL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]
2023-06-30 pines de todo el sistema configurado
2023-07-01 probando con distintas velocidades
2023-07-02 nuevas piezas y modificaciones al ensamble
    [abrazadera.STL, base-principal-p2.SLDPRT, ens_exo_unapieza.SLDASM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]
2023-07-02 medidas de piezas modificadas para mano de rubi
    [base-principal-completa.SLDPRT, base-principal-p2.SLDPRT, ens_exo_unapieza.SLDASM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]
2023-07-03 thumb finger working bug fixed
    [abrazadera.SLDPRT, abrazadera_completa.SLDPRT, abrazadera_completa.STL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]
2023-07-03 funcionan todos los dedos aun hay que resolver muchos bugs
    [main.c, main.h]
2023-07-04 bugs en rutina de home arreglados distancia maxima corregida
    [gui.py, main.c, main.h]
2023-07-09 nuevas piezas para el sobrecalentamiento de los motores
    [abrazadera_completa.SLDPRT, abrazadera_completa.STL, abrazadera_completa_2pza.SLDPRT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]
2023-07-16 ultimos cambios
    [base_bateria_pcb.SLDPRT]
2023-07-24 funcionalidad de angulo y velocidad implementada
2023-07-24 variable timer to pulses for motor speed
2023-07-28 mis cambios en la gui
2023-08-06 variables de velocidad y pasos en seccion de recepcion de comandos
2023-08-19 rutina de home arreglada ahora los botones van primero hacia abajo (adelante) y despues regresan a tocar el boton home
    [main.c]
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2023-08-20 nueva version compilable de codigo, rutina de home mas robusta falta hacer pruebas
2023-08-20 seleccion de dedos correcta
    [gui.py, main.c, main.h]
2023-08-22 minor fixes
    [ens_exo_unapieza.SLDASM, palanca-pulgar.SLDPRT, palanca-pulgar.STL]
2023-08-22 todos los motores van para atras cuando deberian ir adelante al iniciar el programa
2023-08-22 señal de alarma con el indicador led
2023-08-22 varios cambios no funciona aun la rutina de home
2023-08-24 cleaning code trying to fix home routine
    [main.c, main.h]
2023-08-25 home routine fix except for switches failing
    [gui.py, main.c]
2023-08-25 gui redesign, fix fingers in op
    [exoesqueleto.py, gui.py, main.c]
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2023-08-29 Fixing select finger function in c code
    [gui.py, main.c]
2023-09-11 proyecto terminado listo para entrega
    [base_bateria_pcb.SLDPRT, base_bateria_pcb.STL, ens_exo_unapieza.SLDASM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]
2023-11-08 nuevas piezas o modificaciones
    [base_bateria_pcb.SLDPRT, base_bateria_pcb_copia.SLDPRT, base_bateria_pcb_copia.STL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]
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2023-11-08 poder recibir comandos mayores a 3B para posicion
2023-11-09 piezas modificadas solidworks
    [_palanca-menique.SLDPRT, _palanca-menique.STL, ens_exo_unapieza.SLDASM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]

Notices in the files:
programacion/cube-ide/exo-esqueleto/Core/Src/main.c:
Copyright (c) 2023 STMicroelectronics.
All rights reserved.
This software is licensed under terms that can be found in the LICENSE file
